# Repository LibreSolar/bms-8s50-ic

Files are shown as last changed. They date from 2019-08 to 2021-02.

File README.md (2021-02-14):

# BMS 8S50 IC

 First boards tested, some issues might still be open.

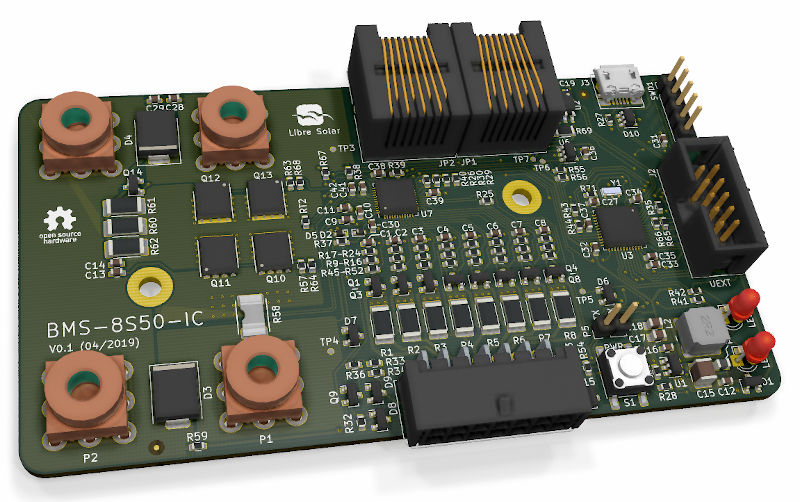
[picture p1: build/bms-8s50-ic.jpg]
BMS 8S50 IC


Schematic: [PDF file](https://github.com/LibreSolar/bms-8s50-ic/raw/master/build/bms-8s50-ic_schematic.pdf)

Bill of Materials: [CSV file](build/bms-8s50-ic_bom.csv) or [interactive HTML BOM](https://libre.solar/bms-8s50-ic/build/bms-8s50-ic_ibom.html)

Firmware repository: [LibreSolar/bms-firmware](https://github.com/LibreSolar/bms-firmware)

## Features:

- 3 to 8 Li-ion cells (e.g. LiFePO4)
- Integrated high-side MOSFET switch and current sensor
- Balancing current approx. 150 mA
- STM32L452 ARM Cortex-M4 microcontroller
- Built-in CAN communication interface and UEXT extension connector

## Firmware

The firmware is developed in a separate repository [LibreSolar/bms-firmware](https://github.com/LibreSolar/bms-firmware).

## Housing

The PCB is designed such that a heat sink can be easily attached at the bottom. The following images show a draft idea for the housing. The files of the heat sink and the cover can be found in the `housing` folder as native FreeCAD files.

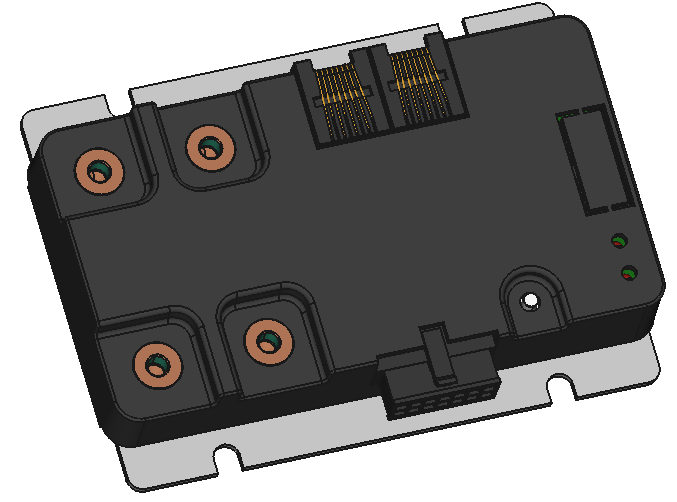
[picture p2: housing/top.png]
Housing top side


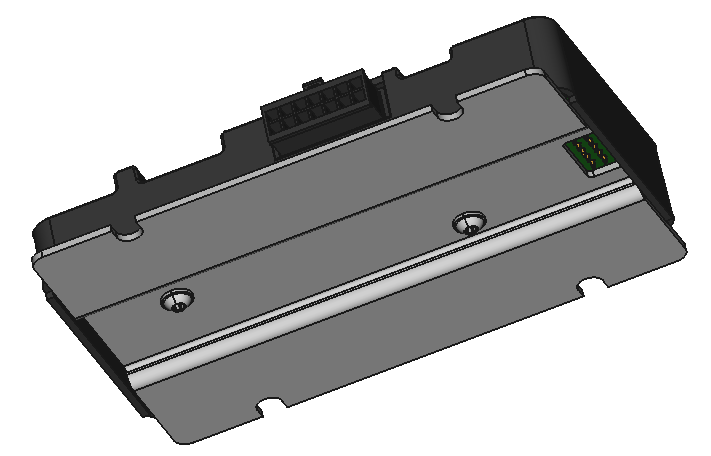
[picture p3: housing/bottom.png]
Housing bottom side with heat sink


## Important Notice

The PCBs have not been tested regarding EMC and other regulations. If you reproduce the boards, you use them at your own risk and responsibility.

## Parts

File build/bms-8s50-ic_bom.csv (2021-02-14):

Component | References | Value | Footprint | Description | Quantity Per PCB | Manufacturer | PartNumber | Remarks | Config | DNF
1 | C37 C41 C42 | 4.7n | C_0603_1608 | Unpolarized capacitor | 3 | Yageo | CC0603KRX7R9BB472
2 | C10 | 10n | C_0603_1608 | Unpolarized capacitor | 1
3 | C1 C2 C3 C4 C5 C6 C7 C8 C20 | 47n | C_0603_1608 | Unpolarized capacitor | 9 | Yageo | CC0603KRX7R9BB473
4 | C13 C14 C16 C19 C27 C28 C29 C31 C32 C33 C34 C36 C38 | 100n | C_0603_1608 | Unpolarized capacitor | 13 | Yageo | CC0603KRX7R9BB104
5 | C30 | 470n | C_0603_1608 | Unpolarized capacitor | 1
6 | C9 C11 C12 | 1u | C_0603_1608 | Unpolarized capacitor | 3 | Murata | GRT188R61H105KE13D | 50V, X5R
7 | C39 | 1u | C_0603_1608 | Unpolarized capacitor | 1
8 | C15 | 4.7u | C_1210_3225 | Unpolarized capacitor | 1 | Murata | GRM31CR71H475MA12L
9 | C21 | 4.7u | C_1206_3216 | Unpolarized capacitor | 1 | Murata | GRM31CR71H475MA12L
10 | C35 | 4.7u | C_0603_1608 | Unpolarized capacitor | 1 | Murata | GRM188R61A475KE15D | 10V
11 | C17 C18 | 10u | C_0805_2012 | Unpolarized capacitor | 2 | Murata | GRM21BR61E106KA73L | 25V
12 | D8 D9 | 12V | D_SOT-23_ANK | Diode zener | 2 | ON Semiconductor | SZBZX84C12LT3G | Alternative: Diodes Inc. BZX84C12-7-F
13 | D1 D6 D7 | BAV70 | SOT-23 | Dual 100V 215mA high-speed switching diodes, common cathode, SOT-23 | 3 | ON Semiconductor | BAV70LT1G | Alternative: Nexperia BAV70,215
14 | D11 D12 | NRVTS260ESFT1G | D_SOD-123 | Schottky diode | 2 | On Semiconductor | NRVTS260ESFT1G | Alternative: Nexperia PMEG6020ER,115
15 | D2 D5 | PMEG6002 | D_SOD-523 | Diode Schottky | 2 | Nexperia | PMEG6002EBF
16 | D3 D4 | SMCJ36A | D_SMC | Diode Schottky | 2 | Bourns | SMCJ24A
17 | D10 | USBLC6-2SC6 | SOT-23-6 |  | 1 | STMicroelectronics | USBLC6-2SC6 | Alternative: WE-TVS 82400102
18 | J1 | Conn_01x10 | Molex_Micro-Fit_3.0_43045-1400_2x07_P3.00mm_Horizontal | Generic connector, double row, 02x07, top/bottom pin numbering scheme (row 1: 1...pins_per_row, row2: pins_per_row+1 ... num_pins), script generated (kicad-library-utils/schlib/autogen/connector/) | 1 | Würth | 66201421022
19 | J2 | UEXT | Box_Header_2x05x2.54mm_Straight | Olimex UEXT connector (2x5 box header) | 1 | Würth | 61201021621
20 | J3 | USB_B_Micro | USB_Micro-B_10103594-0001LF | USB Micro Type B connector | 1 | Amphenol FCI | 10103594-0001LF
21 | JP3 | Jumper_NC_Small | PinHeader_1x02_P2.54mm_Vertical | Jumper, normally closed, small symbol | 1
22 | JP1 JP2 | RJ45_NS | RJ45_8P8C |  | 2 | FCI / Amphenol | 54602-908LF
23 | L1 | 4.7uH | L_0805_2012Metric | Inductor, small symbol | 1 | Murata | LQM21PN4R7NGRD
24 | L2 | 47uH | Bourns_SRN6045TA | Inductor, small symbol | 1 | Tayo Yuden | NR6045T470M | Alternative: Bourns SRR6045TA-470Y
25 | LED1 LED2 | LED | LED_0603_D3.0mm |  | 2
26 | P1 P2 P4 | CONN_01X01 | Wuerth_WP-THRBU_74650195 | Generic screw terminal, single row, 01x01, script generated (kicad-library-utils/schlib/autogen/connector/) | 3 | Wuerth | 74650195
27 | P3 | CONN_01X01 | Wuerth_WP-THRBU_74650195 | Generic screw terminal, single row, 01x01, script generated (kicad-library-utils/schlib/autogen/connector/) | 1 | Wuerth
28 | P5 | CONN_01X02 | PinHeader_1x02_P2.54mm_Vertical | Generic connector, single row, 01x02, script generated (kicad-library-utils/schlib/autogen/connector/) | 1
29 | Q10 Q11 Q12 Q13 | BSC016N06NS | 5X6_MOSFET | Transistor N-MOSFET (general) | 4 | Infineon | BSC016N06NS
30 | Q4 Q5 Q6 Q7 Q8 Q14 Q15 | BSS138 | SOT-23 | Transistor N-MOSFETwith substrate diode (general) | 7 | ON Semiconductor / Fairchild | BSS138
31 | Q1 Q2 Q3 Q9 | NDS0605 | SOT-23 | Transistor P-MOSFET with substrate diode (general) | 4 | ON Semiconductor / Fairchild | NDS0605
32 | R58 | 0.5m | R_Shunt_2512 | Resistor | 1 | Vishay / Dale | WSLF2512L5000FEA | Alternative: Bourns CSS2H-2512R-L500F
33 | R72 | 4R7 | R_0603_1608 | Resistor | 1 | Yageo | RC0603FR-071KL
34 | R1 R2 R3 R4 R5 R6 R7 R8 | 33 | R_2010_5025 | Resistor | 8 | Yageo | RC2010JK-0733RL
35 | R37 R64 R67 R68 R71 | 100 | R_0603_1608 | Resistor | 5 | Yageo | RC0603FR-07100RL
36 | R69 | 120 | R_1206_3216 | Resistor | 1 | Yageo | RC1206FR-07120RL
37 | R60 R61 R62 | 330 | R_2010_5025 | Resistor | 3 | Yageo | RC2010JK-07330RL
38 | R17 R18 R19 R20 R21 R22 R23 R24 R25 R36 R38 R41 R42 R54 | 1k | R_0603_1608 | Resistor | 14 | Yageo | RC0603FR-071KL
39 | R39 R55 R56 R65 R66 | 2.2k | R_0603_1608 | Resistor | 5 | Yageo | RC0603FR-072K2L
40 | R26 R30 R33 R34 R45 R46 R47 R48 R49 R50 R51 R52 | 10k | R_0603_1608 | Resistor | 12 | Yageo | RC0603FR-0710KL
41 | R29 R31 R40 R44 | 22k | R_0603_1608 | Resistor | 4 | Yageo | RC0603FR-0722KL
42 | R28 | 50.5k | R_0603_1608 | Resistor | 1 | Yageo | RC0603FR-0750K5L
43 | R9 R10 R11 R12 R13 R14 R15 R16 R27 R43 R73 | 330k | R_0603_1608 | Resistor | 11 | Yageo | RC0603FR-07330KL
44 | R32 | 1M | R_0603_1608 | Resistor | 1 | Yageo
45 | R35 R53 R57 R63 R70 | 1M | R_0603_1608 | Resistor | 5 | Yageo | RC0603FR-071ML
46 | RT2 | 10k | R_0603_1608 |  | 1 | TDK | NTCG163JF103FT1S
47 | S1 | SW_PUSH | SW_SPST_6mm | Button | 1
48 | SWD1 | ST_Nucleo_SWD_5p | PinHeader_1x05_P2.54mm_Vertical | STM32 Nucleo Board SWD connector (5 pins w/o SWO) | 1
49 | U6 | 24AA32 | SOT-23-5 | Microchip 24AAxx/24LCxx I2C EEPROM, SOT-23-5 | 1 | Microchip | 24AA32AFT-I/OT
50 | U7 | ISL94202 | QFN-48-1EP_6x6mm_P0.4mm_EP4.3x4.3mm | Standalone 3 to 8 Cell Li-Ion Battery Pack Monitor | 1 | Intersil | ISL94202IRTZ-T7A
51 | U3 | STM32L452CCU6 | QFN-48-1EP_7x7mm_P0.5mm_EP5.6x5.6mm | ARM Cortex-M4 MCU, 256KB flash, 160KB RAM, 80MHz, 1.71-3.6V, 38 GPIO, UFQFPN-48 | 1 | ST Microelectronics | STM32L452CCU6
52 | U2 | TCAN334 | SOIC-8_3.9x4.9mm_Pitch1.27mm | High-Speed CAN Transceiver, 1Mbps, 3.3V supply, low power standby mode, shutdown mode, SOT-23-8/SOIC-8 | 1 | Texas Instruments | TCAN334DR
53 | U1 | TPS560430X | SOT-23-6 | SIMPLE SWITCHER® 4V to 60V, 600mA Step-Down Regulator with Low Iq | 1 | Texas Instruments | TPS560430XDBVR
54 | Y1 | 8MHz | Resonator_Murata_CSTNE | Two pin crystal | 1 | Murata | CSTNE8M00GH5C000R0 | 0.07%

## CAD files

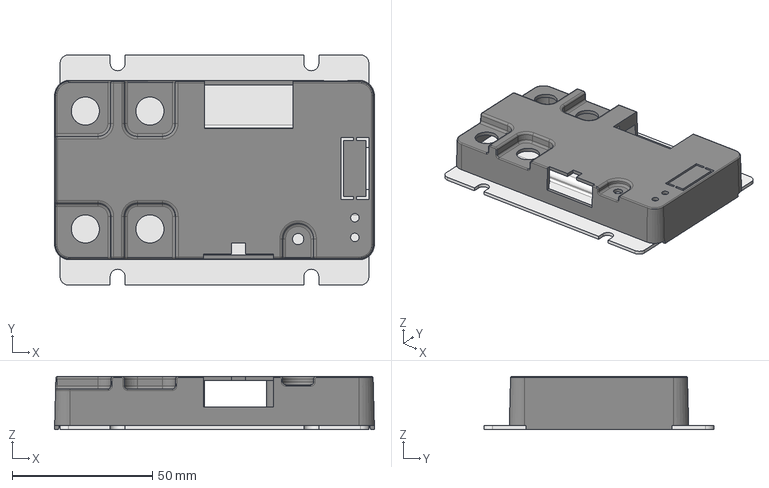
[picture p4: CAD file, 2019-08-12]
housing/bms-8s50-ic.FCStd
114.0 x 82.0 x 19.0 mm
Heatsink
Cover

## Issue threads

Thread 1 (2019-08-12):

Cell connector: Change to JST PH?

martinjaeger, 2019-08-12:
The current PCB uses Würth WR-MPC3 connectors (compatible to Molex Microfit).

These connectors are used quite often in the industry, but not very popular among makers, as they require special crimping tools.

JST PH connectors are quite popular for BMSs on ebay, but are only single-row and require more board space.

Any other good ideas for a connector?

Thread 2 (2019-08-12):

Add marking for Bat+/- and Ext+/- on PCB

martinjaeger, 2019-08-12:
The high power connectors are currently not well marked (forgotten during PCB design).

They should get a marking of the battery-internal +/- terminal and the external (load/charger) +/- terminals.

Closed 2020-05-08.

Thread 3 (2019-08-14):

Add free running diodes parallel to MOSFETs

xsider, 2019-08-14:
Two shottky diodes should be added, parallel to the body diodes inside the MOSFETs. We had maybe a overheating event occured at Switch-N-Sense when huge amount of currenct was sink from the battery while the charge mosfet was open, so the body diode was used. The body diode is a bad one (big voltage drop).

martinjaeger, 2019-08-14:
This can be solved in firmware with improved control (ideal diode control). Monitor the current and as soon as it goes into discharging direction switch on the charge MOSFET even if charging is not allowed at that moment.

martinjaeger, 2019-08-18:
Just saw that the ISL94202 supports ideal diode control out of the box. Look at the DFODUV and CFODOV settings.

martinjaeger, 2019-08-18:
Closing this issue, as solutions without hardware change exist. Please reopen if you disagree.

martinjaeger, 2021-06-24:
FYI: I have implemented the ideal diode control today.

https://github.com/LibreSolar/bms-firmware/commit/42f2da214415df28c67f6d3dba1b5db2b75b85b2

Closed 2019-08-18.

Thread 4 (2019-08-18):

Increase shunt resistor value for higher charge current

martinjaeger, 2019-08-18:
The ISL94202 allows maximum 24 mV as charge overcurrent threshold. This corresponds to only 24 A using the current 1 mOhm shunt.

The resistor value should be lowered to 0.5 or 0.4 mOhm.

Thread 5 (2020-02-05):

voltage measurement of cell 1

MatthiasN73, 2020-02-05:
Hi,
I recently finished building the bms-8s50 and encountered a problem with the voltage measurement of cell 1. The measurement is very instable. the voltage oscillates by approximately 200 mV and is about 500 mV to low. After some investigations and bridging R59 the oscillation is gone and near the real value but still to low (150 mV). What is the function of R59?
By the way I studied the datasheet of the ISL94202 and found some issues:
a missing capacitor between VC0 and Ground (47nF)
a missing resistor (1M) between source and gate of Q10 (PCFET)
wrong value of C30 should be a 470nF capacitor
If I have understood the datasheet correctly, the Precharge path should bridge the charge fet in case of to low voltage of one or more cells. But in your case the discharge fet is bridged. Why?

sorry for my english.

martinjaeger, 2020-02-06:
Hi Matthias,
very cool that you rebuilt the BMS. Unfortunately I didn't have much time for it in the past months, so there was not too much progress in testing and firmware of the BMS.

I didn't have any issues with cell voltage measurements in my 4s battery pack so far. But I'll double-check.

The idea for R59 was to decouple the power path from the analog measurement ground. I actually took this idea from the [DieBieMS](https://github.com/DieBieEngineering/DieBieMS).

You are right, a capacitor between VC0 and GND is missing. This might cause some noise in cell 1 measurement, but it should not result in 150 mV offset... but it's definitely an error that should be corrected in next revision. It could be possible to add the capacitor manually attached to R25 in current PCB layout.

Also the value of C30 is wrong, I agree.

I'm using the precharge circuit different from what is stated in the datasheet. I use it to precharge the capacitors of devices connected to the battery before switching the discharge MOSFET on. This prevents high inrush currents. I don't really see the point of precharging the battery (not the capacitors) slowly via resistors, as the BMS could just tell the charger to use low current.

Are you using the new Zephyr-based firmware or did you develop something else yourself?

MatthiasN73, 2020-02-06:
Hello Martin,
Thanks for your quick response.
In my configuration, I use all 8 cells.
I would like to use the zephyr version, but there is no board definition for the STM32F072 mcu and so I cannot flash the compiled firmware.
To get the bms working, I just completed the missing function “isl94202_write_bytes” and “isl94202_read_bytes” in the mbed-version.

martinjaeger, 2020-02-06:
As I'm now quite used to Zephyr, it shouldn't be that much effort to add a board definition for the STM32F072 MCU. I'll try to include that.

However, as I soldered the L4 MCU onto my board, I can't test it for the new BMS.

martinjaeger, 2020-02-06:
Please have a try: https://github.com/LibreSolar/bms-firmware/commit/85969f8416860dc9ba5ee1d79ab26c3384f68910

MatthiasN73, 2020-02-10:
Unfortunately I can’t compile the firmware. Seems to be too big.
The following Errors appear:
firmware-pre.elf section `bss' will not fit in region `SRAM'
region `SRAM' overflowed by 13320 bytes
Any idea?

martinjaeger, 2020-02-10:
Oh yes, the heap size was way too high (which is not necessary). Reduced it to 1024 bytes. Please `git pull` and try again.

Here is the change: https://github.com/LibreSolar/bms-firmware/commit/0e6d23e10f0c196ae55d72aa18770a512bd60185

MatthiasN73, 2020-02-10:
Now build and upload works. Thanks again.

MatthiasN73, 2020-02-10:
This is an automatic reply to your message

 ---------------------------------------------------------------------
 Sie haben eine E-Mail an die Adresse m.neubauer@schenk-ansorge.de geschickt.
 Leider bin ich bis einschließlich 14.02.2020 18:00  nicht im Labor.
 In dringenden Fällen wenden Sie sich bitte an Herrn Gerhard unter
 der Telefonnummer 0391/24468-246 bzw. F.Gerhard@schenk-ansorge.de

 Vielen Dank für Ihr Verständnis.

 ---------------------------------------------------------------------

 File names:    

Oh yes, the heap size was way too high (which is not necessary). Reduced it to 1024 bytes. Please `git pull` and try again.

Here is the change: https://github.com/LibreSolar/bms-firmware/commit/0e6d23e10f0c196ae55d72aa18770a512bd60185

--
You are receiving this because you authored the thread.
Reply to this email directly or view it on GitHub:
https://github.com/LibreSolar/bms-8s50-ic/issues/5#issuecomment-584024162

MatthiasN73, 2020-04-19:
Hi Martin,

after further investigation and reading then ISL94202 datasheet, i discovered the potential cause of this issue.
The VDD Pin of the ISL94202 should conntected to the top of the pack through a low pass filter consisting of a <10 Ohm resistor and a 4.7μF capacitor.
In your circuit VDD is connected through the VBATT low pass filter with an resistor of 100 Ohm.
Currently i've connected D2 through a separat low pass filter (4,7 Ohm / 4.7μF) to BAT+. Now the volatage measurment is okay.
By the way i replaced C39 with a 1µF capacitor, C30 with a 470nF capacitor and add the missing 47nF capacitor at VC0.

Furthermore i increased the shunt resistor to 0.3 mOhm, but the displayed current does'nt match the measured value of my multimeter.
Any ideas?

martinjaeger, 2020-04-23:
Hi Matthias,

just checked with my BMS here and realized that the current measurement is pretty accurate above 1A, but more than 20% off at very low currents.

The reason may be that the firmware doesn't adjust the current sense amplfier gain yet, it is always kept at the default setting (gain 50). The accuracy will probably become better if it is set to 500.

Great that you found the reason for the issue with VBATT measurement. Didn't have time to test it yet, but will try to do that soon, together with fixing the capacitor values. Afterwards I will also update board and schematic :)

martinjaeger, 2020-05-08:
Soldered all the updates you suggested above to my board. Looks a bit ugly now :)

Also the KiCad files should now include all the identified fixes. Please have a look if I forgot something.

I hoped that the added capacitors would also solve the incorrect pack voltage measurement (see [here](https://github.com/LibreSolar/bms-firmware/blob/8ff63999a65384dbe5ab18886f27a3f042b34043/src/bms_isl94202.c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)). Unfortunately, that was not the case here. Did you try out if the pack voltage measurement provided by the chip is correct? I get a pack voltage of around 12.8V, but sum of single cell voltages is 13.1V, which is also what my multimeter tells me.

The shunt resistor is not updated yet (still need to decide which value is suitable, as the current measurement gets inaccurate if the shunt value is too small, as you have seen as well).

MatthiasN73, 2020-05-09:
Hi Martin,

looks good. I replaced the R59 by a 0R resistor, because it affects the measurement as well.
The pack voltage i messured with my multimeter ist 31.0 V (it's a 8S LIPO pack) and the ISL tells a voltage of 31.16.
I think it's pretty okay.

martinjaeger, 2020-05-09:
Ok, that might in fact be the reason. Will try that out aswell and let you know the result.

martinjaeger, 2020-05-11:
Morning! Just had a try with R59 as 0R, but it didn't really improve the pack voltage reading.

Just for clarification: Did you measure above stated values via the ISL94202_VBATT register or with the sum of all single cell voltages (which is how the pack voltage is currently calculated in the firmware).
If I comment out the line referenced above I still get a pack voltage of 12.91V (instead of 13.32V if using the sum of all single cell voltages). The actual voltage measured with the Fluke Multimeter is 13.33V. So the sum of cell voltages is very accurate, while the pack voltage is not at all...

MatthiasN73, 2020-05-11:
Yes, i activated the pack voltage measurement by reading ISL94202_VBATT register.  My multimeter is just a simple PEAKTECH 3335. Maybe it's not very precisely. Will try out the summation of all cells and compare it with the VBATT register value tomorrow.

MatthiasN73, 2020-05-11:
Hi, here are my results:
- sum of cells voltage: 29.68 V
- result of reading VBATT register: 29.79 V
- measurement with multimeter: 29.6 V
I think, this is an acceptable deviation (< 0,5%).

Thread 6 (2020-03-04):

Add pull-down to +5V

martinjaeger, 2020-03-04:
The 5V power supply is floating if no USB is connected. In some cases it was >1V and enabled the SMPS again immediately after shutdown (via D6). A weak pull-down helps to prevent this.

Other option: Remove D6 completely and switch on only via RGO. In that case, the MCU can't be powered if no battery is connected. But that is probably not an issue.

Closed 2020-05-08.

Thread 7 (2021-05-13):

Bus precharge using PCFET pin does not work as intended

martinjaeger, 2021-05-13:
The idea was to use the pin originally intended for slow charging of a deep-discharged battery to slowly charge bus capacitors and prevent high discharge current through the FETs during turn-on.

This does not work as intended, as the gate of Q14 is kept at the top cell voltage and thus allows continuous discharge current through the precharge resistors if EXT+ is pulled low.

Workaround (not using the bus precharge anymore) is to remove Q14.

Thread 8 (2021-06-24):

Strange behaviour of ISL94202 shuts off FETs at 55°C

martinjaeger, 2021-06-24:
According to the ISL94292 manual, xT2 can be used to monitor the FETs.

However, the temperature limit of the FETs is not configurable. If `XT2M` is set to 1 to indicate that it's not measuring cell temperatures, the FETs are still switched off if the temperature at xT2 reaches 55°C and back on when the temperature drops to 50°C again. These thresholds are the same as the default cell overtemperature thresholds, but they don't seem to be read from the same registers.

Below image shows a test where in a first step xT2 (MOSFETs) was heated up (by charging through body diode while discharge FET was off). Afterwards, the external sensor connected to xT1 (Battery) was heated up with a heat gun. As it can be seen, the same error flags are raised (COTF and DOTF). The cell temperature limit is set to 45°C, re-connect to 40°C, which is working fine. The xT2 limits of 55°C and 50°C are not affected.

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

This strange (undocumented) behaviour of the chip is also confirmed here:
https://renesasrulz.com/general/f/general---forum/15530/isl94202-demo-board-fet-temp-issue

Possible solutions (in hardware):

1. Use thermistor directly wired to microcontroller.
2. Adjust xT2 thermistor network to match desired maximum measured MOSFET temperature.

martinjaeger, 2021-06-24:
Interestingly, it's now picking up the same temperature setpoints as the cell overtemperature:

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

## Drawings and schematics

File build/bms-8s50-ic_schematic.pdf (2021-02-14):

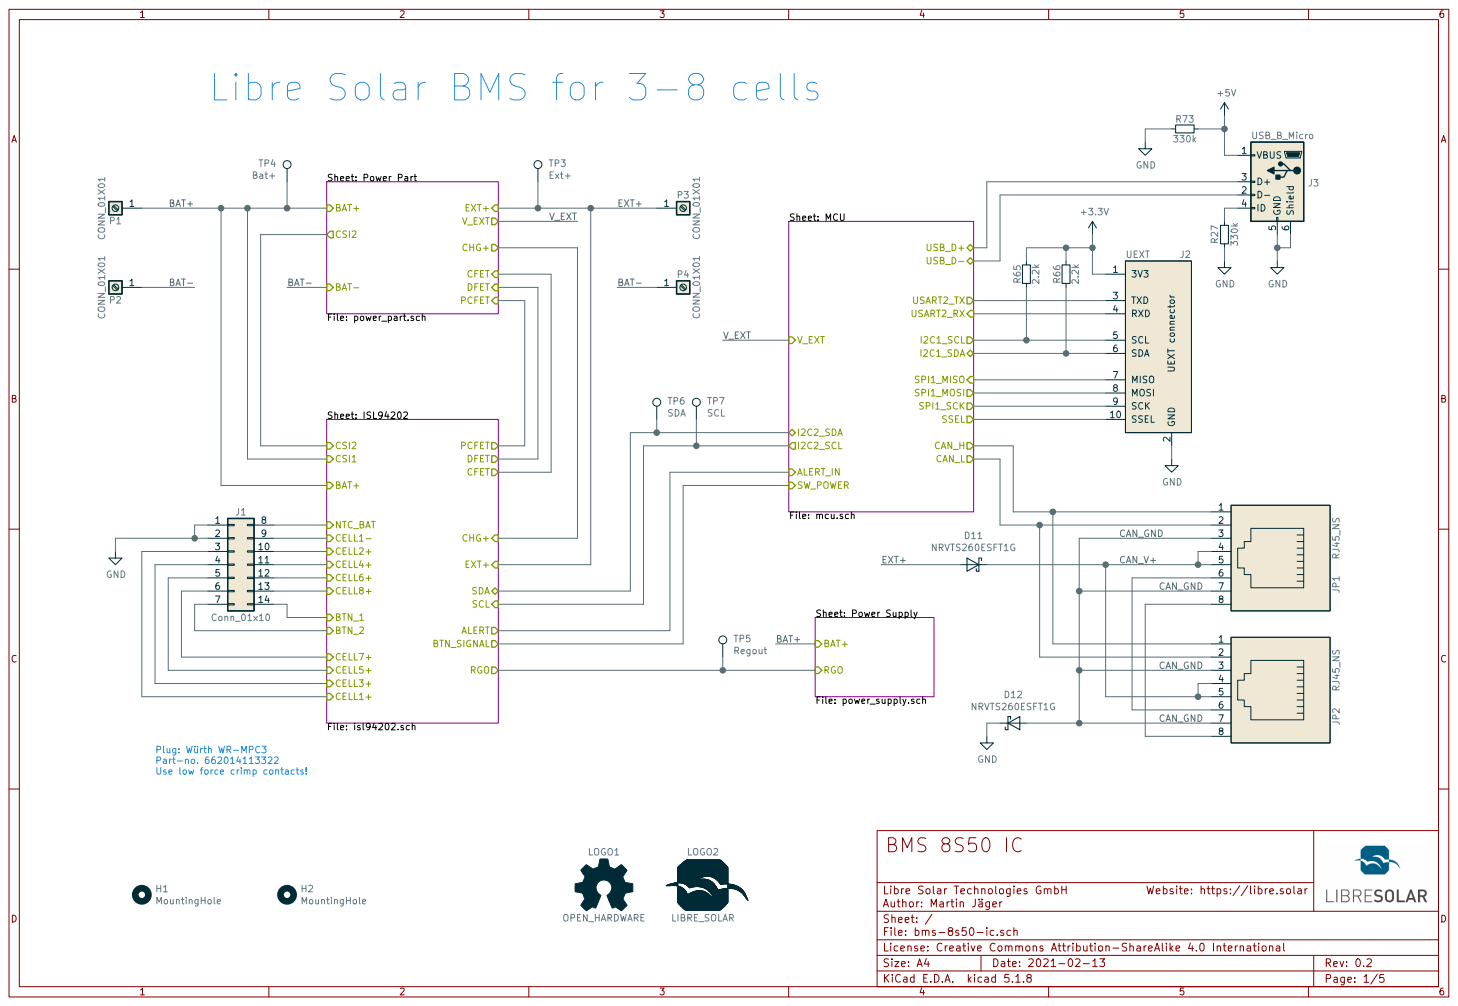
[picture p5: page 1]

Libre Solar BMS for 3-8 cells

2 TXD 3 SCL 5 SDA 6 MISO 7 MOSI 8 SCK 9 UEXT J2

V_EXT BAT- Plug: Würth WR-MPC3 Part-no. 662014113322 Use low force crimp contacts!

CAN_GND 3

Author: Martin Jäger License: Creative Commons Attribution-ShareAlike 4.0 International

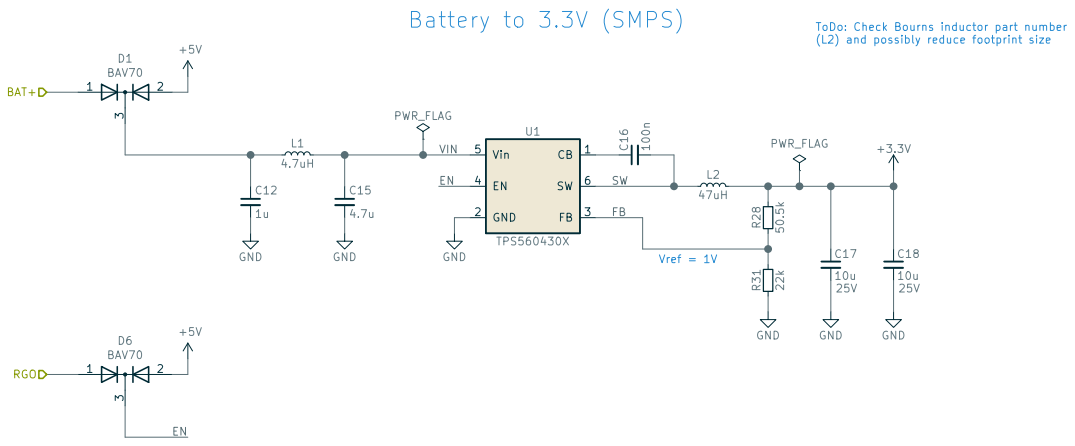
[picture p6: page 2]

(L2) and possibly reduce footprint size Vref = 1V

Author: Martin Jäger License: Creative Commons Attribution-ShareAlike 4.0 International
Sheet: /Power Supply/
File: power_supply.sch

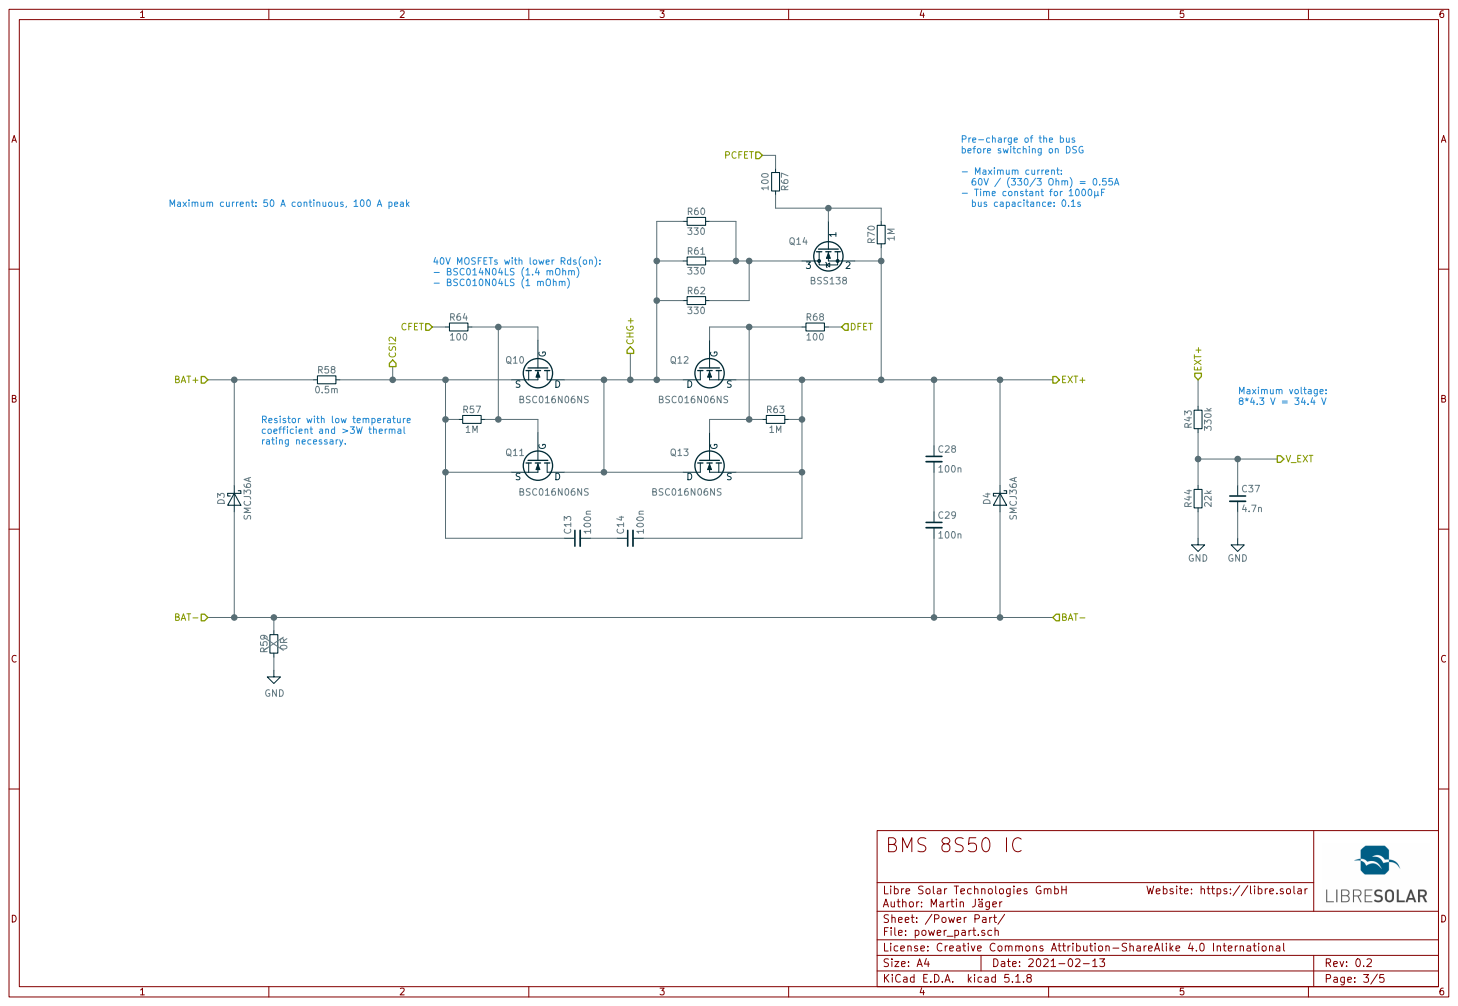
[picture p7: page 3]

Pre-charge of the bus
before switching on DSG

Maximum current: 50 A continuous, 100 A peak

40V MOSFETs with lower Rds(on):
- BSC014N04LS (1.4 mOhm)
- BSC010N04LS (1 mOhm)

Resistor with low temperature
coefficient and >3W thermal rating necessary.

Author: Martin Jäger License: Creative Commons Attribution-ShareAlike 4.0 International

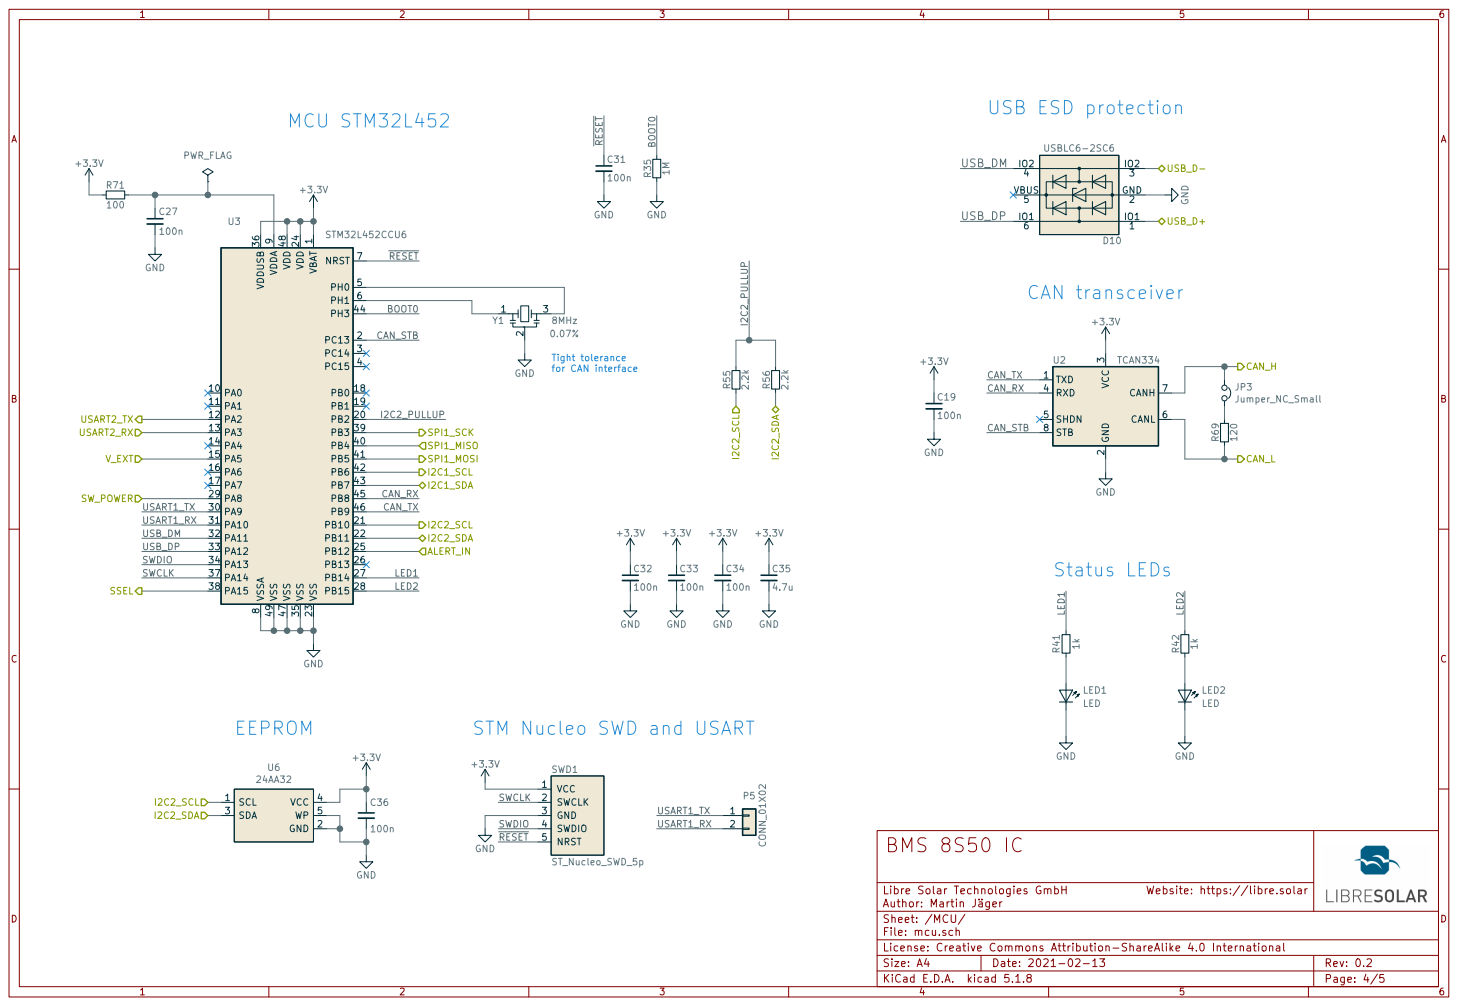
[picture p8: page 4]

3 RXD 4 SHDN 5 CANL 6 CANH 7 STB 8 U2 TCAN334 R71

8 U3 STM32L452CCU6 GND 2 VCC 4 SCL 1 SDA 3 WP 5 U6

9 VDDUSB 36 VSS 23 VSS 35 VSS 47 VSS 49 VSSA

LED GND
STM Nucleo SWD and USART

Author: Martin Jäger License: Creative Commons Attribution-ShareAlike 4.0 International

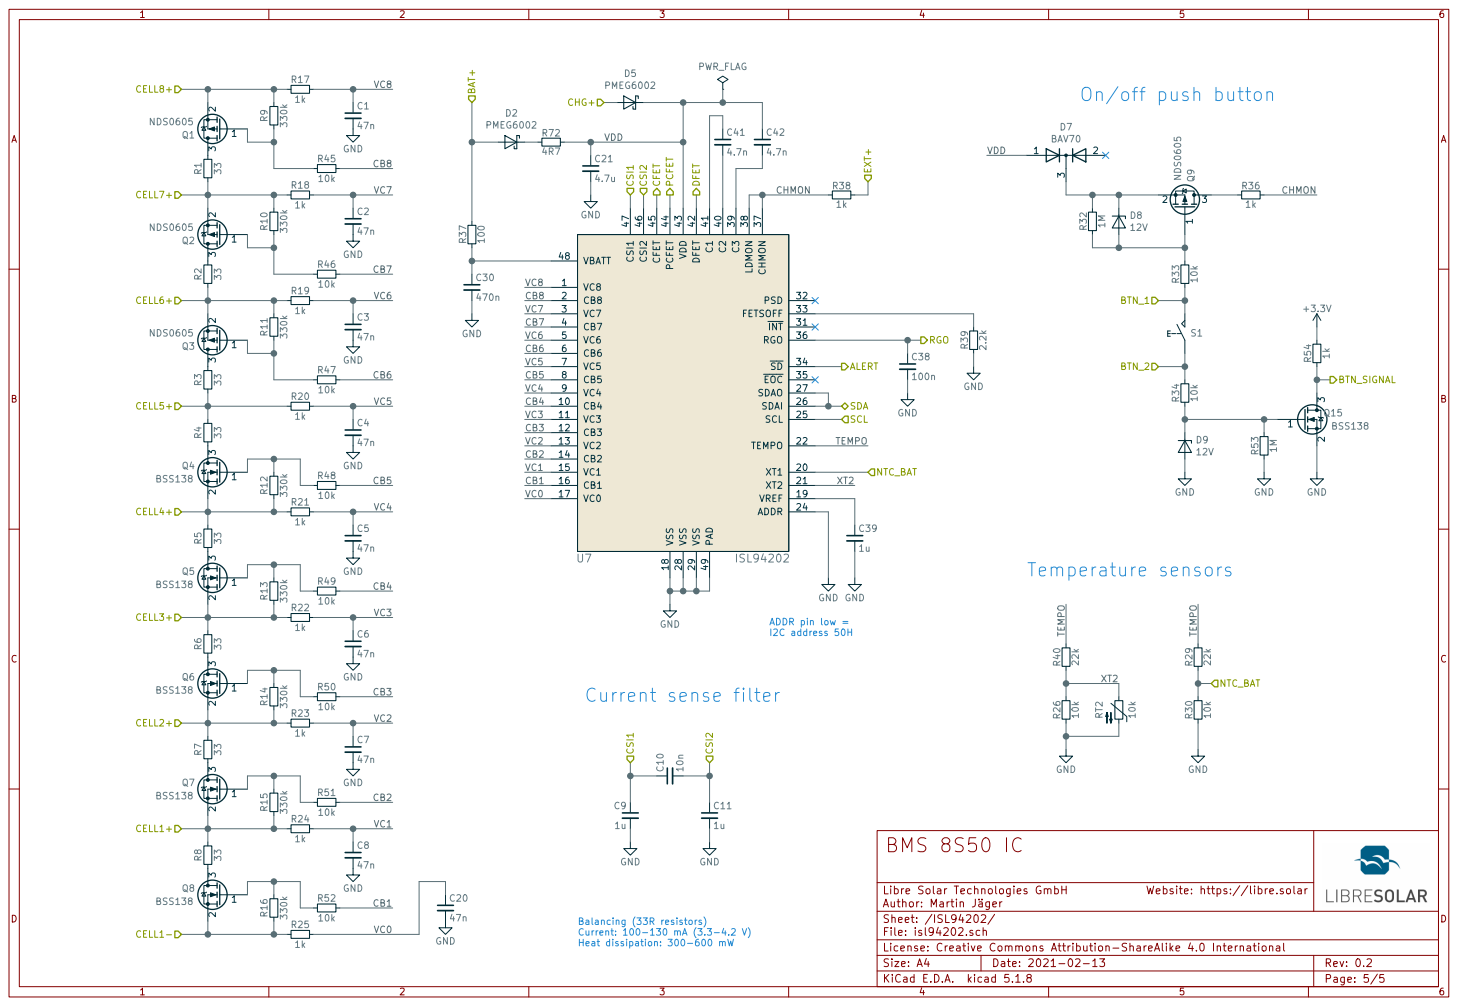
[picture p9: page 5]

On/off push button

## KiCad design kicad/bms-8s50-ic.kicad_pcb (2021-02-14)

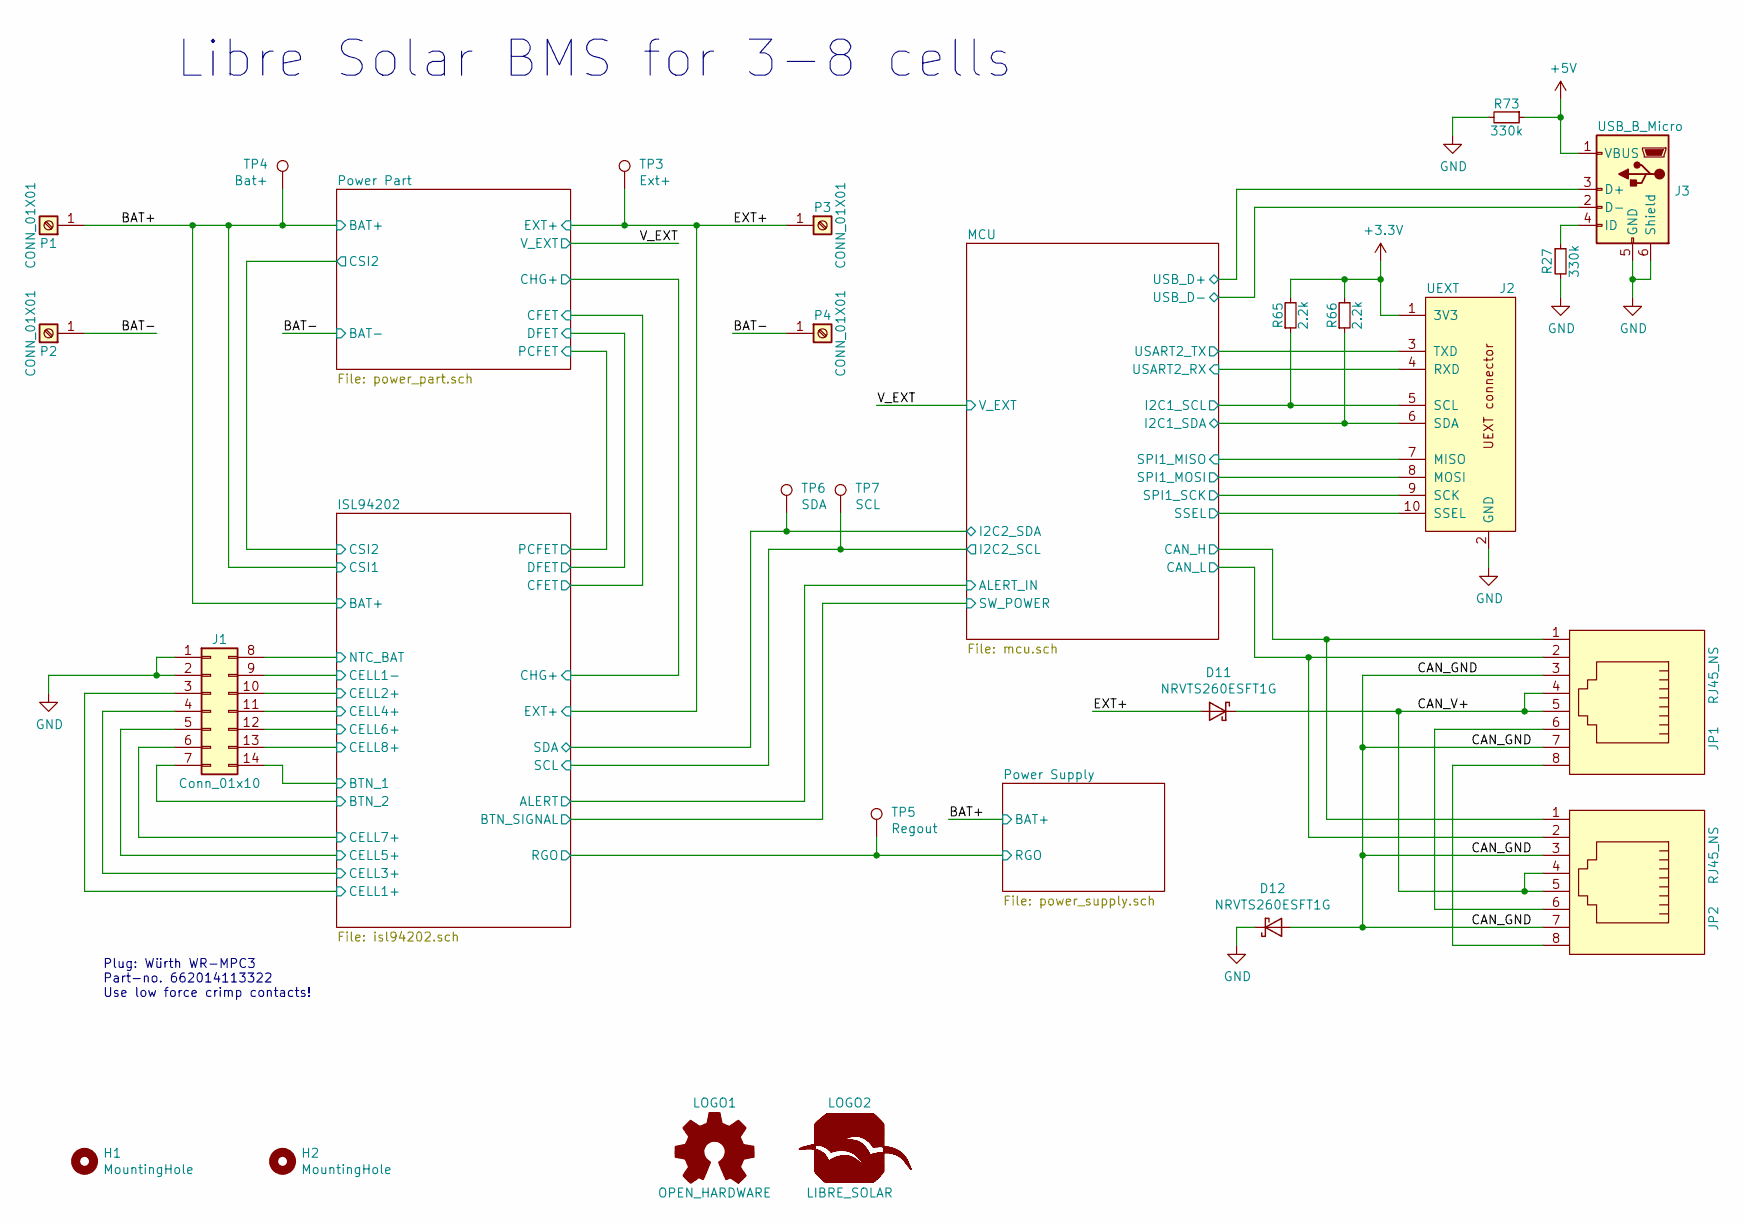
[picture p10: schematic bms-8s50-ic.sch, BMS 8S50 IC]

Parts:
D11, D12: NRVTS260ESFT1G; D_SOD-123; PartNumber NRVTS260ESFT1G
H1, H2: MountingHole; MountingHole_3.2mm_M3_Pad
J1: Conn_01x10; Molex_Micro-Fit_3.0_43045-1400_2x07_P3.00mm_Horizontal; PartNumber 66201421022
J2: UEXT; Box_Header_2x05x2.54mm_Straight; PartNumber 61201021621
J3: USB_B_Micro; USB_Micro-B_10103594-0001LF; PartNumber 10103594-0001LF
JP1, JP2: RJ45_NS; RJ45_8P8C; PartNumber 54602-908LF
LOGO1: OPEN_HARDWARE; OSHW-Logo_5.7x6mm_SilkScreen
LOGO2: LIBRE_SOLAR; LIBRESOLAR_LOGO
P1, P2, P4: CONN_01X01; Wuerth_WP-THRBU_74650195; PartNumber 74650195
P3: CONN_01X01; Wuerth_WP-THRBU_74650195
R27, R73: 330k; R_0603_1608; PartNumber RC0603FR-07330KL
R65, R66: 2.2k; R_0603_1608; PartNumber RC0603FR-072K2L
TP3: Ext+; TestPoint_1mm_pad
TP4: Bat+; TestPoint_1mm_pad
TP5: Regout; TestPoint_1mm_pad
TP6: SDA; TestPoint_1mm_pad
TP7: SCL; TestPoint_1mm_pad

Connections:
+3V3: J2.1 (3V3), R65.2, R66.2; also elsewhere on the board
+5V: J3.1 (VBUS), R73.1; also elsewhere on the board
/BAT+: P1.1, TP4.1; also elsewhere on the board
/BAT-: P2.1, P4.1; also elsewhere on the board
/CAN_GND: D12.2 (A), JP1.3, JP1.7, JP2.3, JP2.7
/CAN_V+: D11.1 (K), JP1.4, JP1.5, JP2.4, JP2.5
/EXT+: D11.2 (A), P3.1, TP3.1; also elsewhere on the board
/ISL94202/BTN_1: J1.14; also elsewhere on the board
/ISL94202/BTN_2: J1.7; also elsewhere on the board
/ISL94202/CELL1+: J1.3; also elsewhere on the board
/ISL94202/CELL1-: J1.9; also elsewhere on the board
/ISL94202/CELL2+: J1.10; also elsewhere on the board
/ISL94202/CELL3+: J1.4; also elsewhere on the board
/ISL94202/CELL4+: J1.11; also elsewhere on the board
/ISL94202/CELL5+: J1.5; also elsewhere on the board
/ISL94202/CELL6+: J1.12; also elsewhere on the board
/ISL94202/CELL7+: J1.6; also elsewhere on the board
/ISL94202/CELL8+: J1.13; also elsewhere on the board
/ISL94202/NTC_BAT: J1.8; also elsewhere on the board
/ISL94202/RGO: TP5.1; also elsewhere on the board
/MCU/CAN_H: JP1.1, JP2.1; also elsewhere on the board
/MCU/CAN_L: JP1.2, JP2.2; also elsewhere on the board
/MCU/I2C1_SCL: J2.5 (SCL), R65.1; also elsewhere on the board
/MCU/I2C1_SDA: J2.6 (SDA), R66.1; also elsewhere on the board
/MCU/I2C2_SCL: TP7.1; also elsewhere on the board
/MCU/I2C2_SDA: TP6.1; also elsewhere on the board
/MCU/SPI1_MISO: J2.7 (MISO); also elsewhere on the board
/MCU/SPI1_MOSI: J2.8 (MOSI); also elsewhere on the board
/MCU/SPI1_SCK: J2.9 (SCK); also elsewhere on the board
/MCU/SSEL: J2.10 (SSEL); also elsewhere on the board
/MCU/USART2_RX: J2.4 (RXD); also elsewhere on the board
/MCU/USART2_TX: J2.3 (TXD); also elsewhere on the board
/MCU/USB_D+: J3.3 (D+); also elsewhere on the board
/MCU/USB_D-: J3.2 (D-); also elsewhere on the board
GND: D12.1 (K), J1.1, J1.2, J2.2 (GND), J3.5 (GND), J3.6 (Shield), R27.2, R73.2; also elsewhere on the board
unnamed: J3.4 (ID), R27.1
unnamed: JP1.6, JP2.6
unnamed: JP1.8, JP2.8

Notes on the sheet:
Plug: Würth WR-MPC3 Part-no. 662014113322 Use low force crimp contacts!
Libre Solar BMS for 3-8 cells

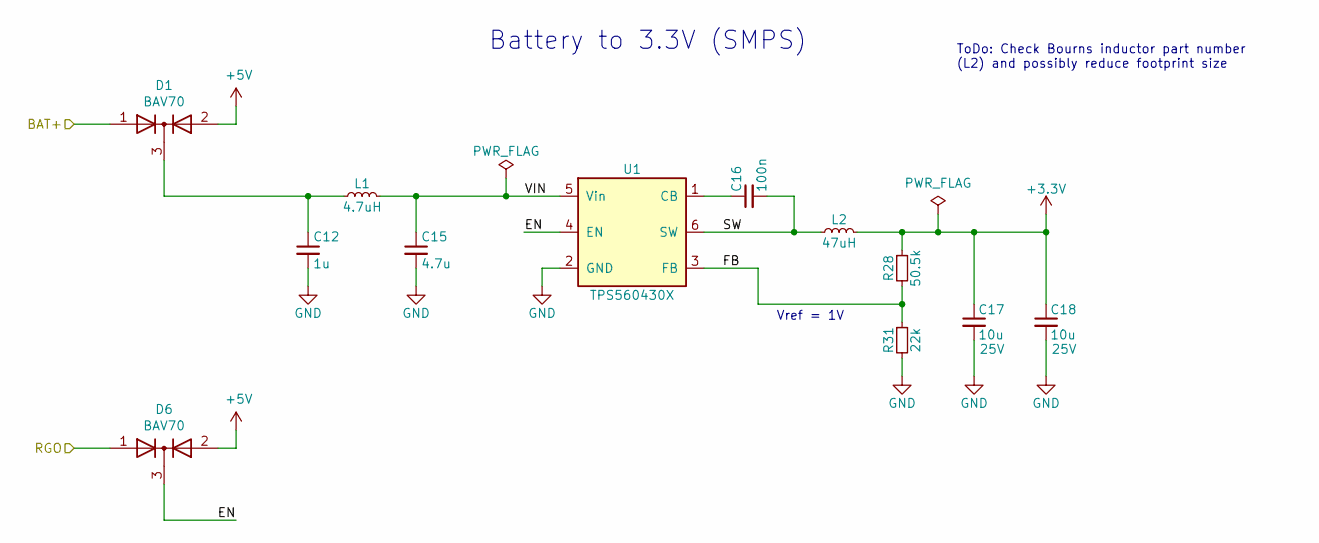
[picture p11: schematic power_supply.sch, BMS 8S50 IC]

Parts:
C12: 1u; C_0603_1608; PartNumber GRT188R61H105KE13D
C15: 4.7u; C_1210_3225; PartNumber GRM31CR71H475MA12L
C16: 100n; C_0603_1608; PartNumber CC0603KRX7R9BB104
C17, C18: 10u; C_0805_2012; PartNumber GRM21BR61E106KA73L
D1, D6: BAV70; SOT-23; PartNumber BAV70LT1G
L1: 4.7uH; L_0805_2012Metric; PartNumber LQM21PN4R7NGRD
L2: 47uH; Bourns_SRN6045TA; PartNumber NR6045T470M
R28: 50.5k; R_0603_1608; PartNumber RC0603FR-0750K5L
R31: 22k; R_0603_1608; PartNumber RC0603FR-0722KL
U1: TPS560430X; SOT-23-6; PartNumber TPS560430XDBVR

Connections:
+3V3: C17.1, C18.1, L2.2, R28.1; also elsewhere on the board
+5V: D1.2 (A), D6.2 (A); also elsewhere on the board
/BAT+: D1.1 (A); also elsewhere on the board
/ISL94202/RGO: D6.1 (A); also elsewhere on the board
/Power Supply/EN: D6.3 (K), U1.4 (EN)
/Power Supply/FB: R28.2, R31.1, U1.3 (FB)
/Power Supply/SW: C16.2, L2.1, U1.6 (SW)
/Power Supply/VIN: C15.1, L1.2, U1.5 (Vin)
GND: C12.2, C15.2, C17.2, C18.2, R31.2, U1.2 (GND); also elsewhere on the board
unnamed: C12.1, D1.3 (K), L1.1
unnamed: C16.1, U1.1 (CB)

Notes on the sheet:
Battery to 3.3V (SMPS)
ToDo: Check Bourns inductor part number (L2) and possibly reduce footprint size
Vref = 1V

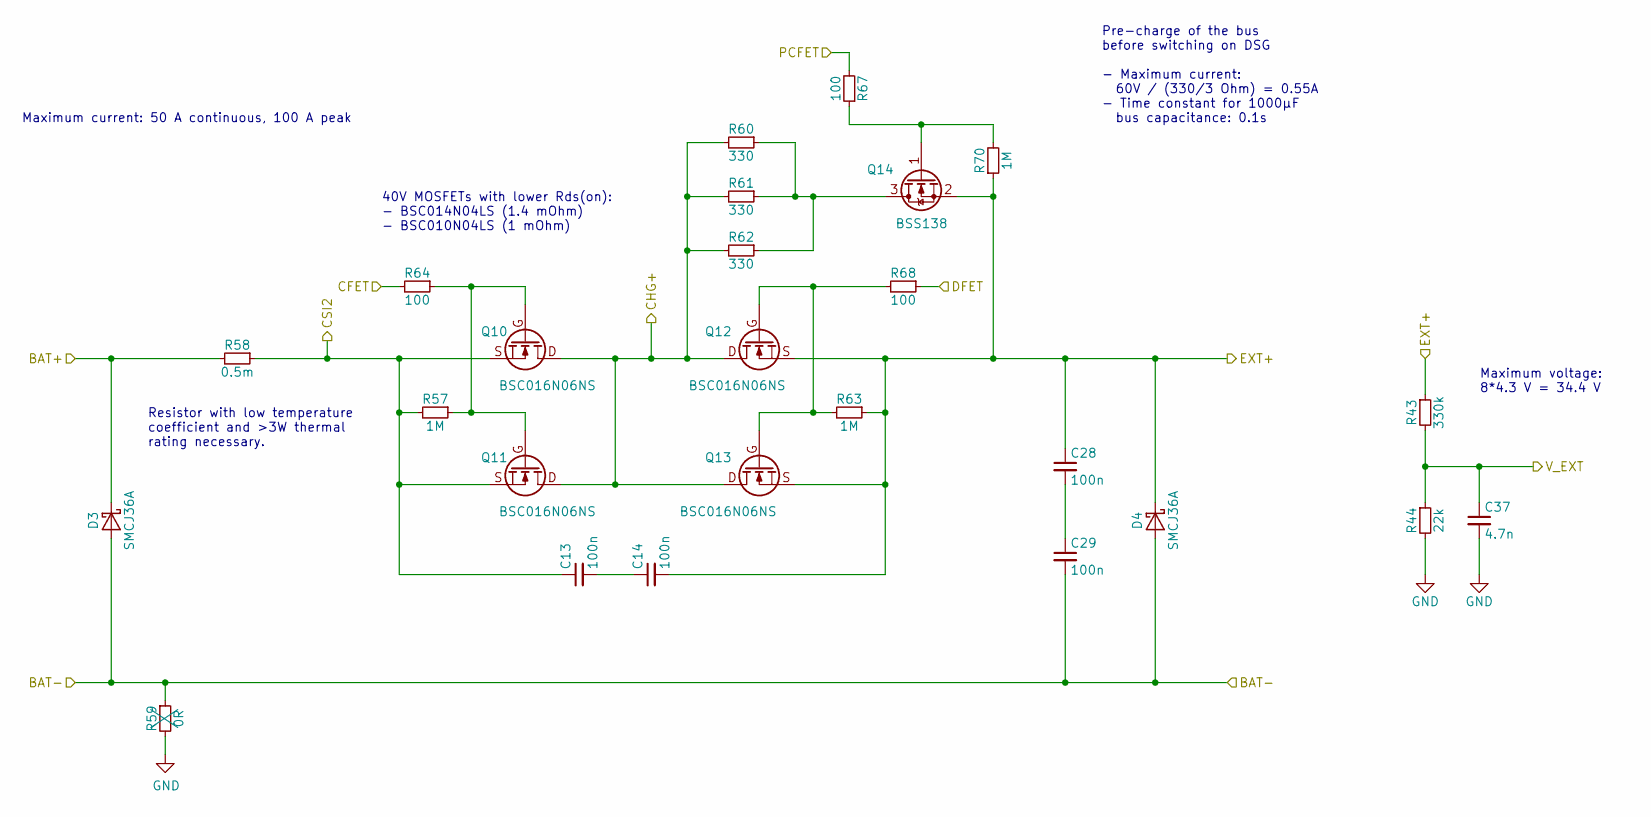
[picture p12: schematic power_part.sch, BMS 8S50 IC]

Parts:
C13, C14, C28, C29: 100n; C_0603_1608; PartNumber CC0603KRX7R9BB104
C37: 4.7n; C_0603_1608; PartNumber CC0603KRX7R9BB472
D3, D4: SMCJ36A; D_SMC; PartNumber SMCJ24A
Q10, Q11, Q12, Q13: BSC016N06NS; 5X6_MOSFET; PartNumber BSC016N06NS
Q14: BSS138; SOT-23; PartNumber BSS138
R43: 330k; R_0603_1608; PartNumber RC0603FR-07330KL
R44: 22k; R_0603_1608; PartNumber RC0603FR-0722KL
R57, R63, R70: 1M; R_0603_1608; PartNumber RC0603FR-071ML
R58: 0.5m; R_Shunt_2512; PartNumber WSLF2512L5000FEA
R59: 0R; R_0603_1608; PartNumber RC0603FR-070RL
R60, R61, R62: 330; R_2010_5025; PartNumber RC2010JK-07330RL
R64, R67, R68: 100; R_0603_1608; PartNumber RC0603FR-07100RL

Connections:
/BAT+: D3.1 (K), R58.2; also elsewhere on the board
/BAT-: C29.2, D3.2 (A), D4.2 (A), R59.1; also elsewhere on the board
/EXT+: C14.2, C28.1, D4.1 (K), Q12.S, Q13.S, Q14.2 (S), R43.1, R63.1, R70.1; also elsewhere on the board
/ISL94202/CFET: R64.2; also elsewhere on the board
/ISL94202/CHG+: Q10.D, Q11.D, Q12.D, Q13.D, R60.2, R61.2, R62.2; also elsewhere on the board
/ISL94202/CSI2: C13.1, Q10.S, Q11.S, R57.2, R58.1; also elsewhere on the board
/ISL94202/DFET: R68.1; also elsewhere on the board
/ISL94202/PCFET: R67.2; also elsewhere on the board
/V_EXT: C37.1, R43.2, R44.1; also elsewhere on the board
GND: C37.2, R44.2, R59.2; also elsewhere on the board
unnamed: C13.2, C14.1
unnamed: C28.2, C29.1
unnamed: Q10.G, Q11.G, R57.1, R64.1
unnamed: Q12.G, Q13.G, R63.2, R68.2
unnamed: Q14.1 (G), R67.1, R70.2
unnamed: Q14.3 (D), R60.1, R61.1, R62.1

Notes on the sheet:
Pre-charge of the bus before switching on DSG - Maximum current: 60V / (330/3 Ohm) = 0.55A - Time constant for 1000µF bus capacitance: 0.1s
Resistor with low temperature coefficient and >3W thermal rating necessary.
Maximum current: 50 A continuous, 100 A peak
40V MOSFETs with lower Rds(on): - BSC014N04LS (1.4 mOhm) - BSC010N04LS (1 mOhm)
Maximum voltage: 8*4.3 V = 34.4 V

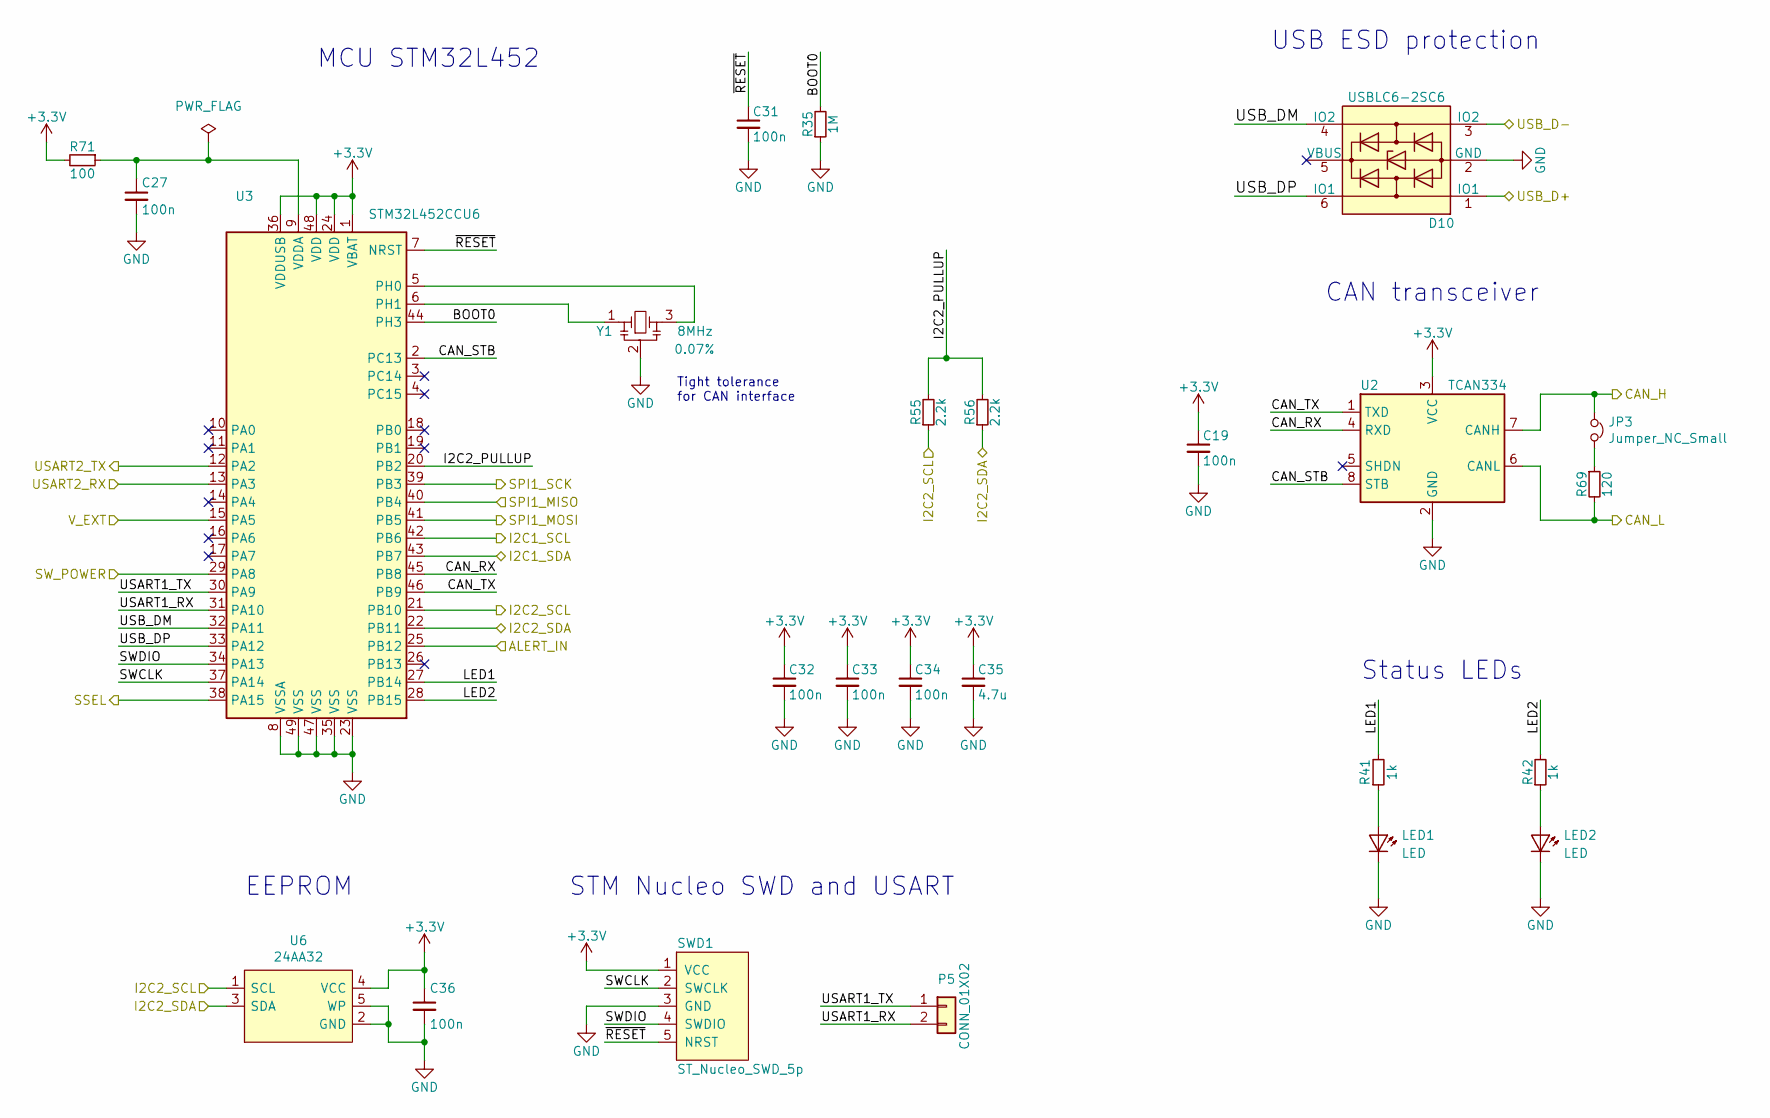
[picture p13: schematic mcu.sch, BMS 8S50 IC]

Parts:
C19, C27, C31, C32, C33, C34, C36: 100n; C_0603_1608; PartNumber CC0603KRX7R9BB104
C35: 4.7u; C_0603_1608; PartNumber GRM188R61A475KE15D
D10: USBLC6-2SC6; SOT-23-6; PartNumber USBLC6-2SC6
JP3: Jumper_NC_Small; PinHeader_1x02_P2.54mm_Vertical
LED1, LED2: LED; LED_0603_D3.0mm
P5: CONN_01X02; PinHeader_1x02_P2.54mm_Vertical
R35: 1M; R_0603_1608; PartNumber RC0603FR-071ML
R41, R42: 1k; R_0603_1608; PartNumber RC0603FR-071KL
R55, R56: 2.2k; R_0603_1608; PartNumber RC0603FR-072K2L
R69: 120; R_1206_3216; PartNumber RC1206FR-07120RL
R71: 100; R_0603_1608; PartNumber RC0603FR-07100RL
SWD1: ST_Nucleo_SWD_5p; PinHeader_1x05_P2.54mm_Vertical
U2: TCAN334; SOIC-8_3.9x4.9mm_Pitch1.27mm; PartNumber TCAN334DR
U3: STM32L452CCU6; QFN-48-1EP_7x7mm_P0.5mm_EP5.6x5.6mm; PartNumber STM32L452CCU6
U6: 24AA32; SOT-23-5; PartNumber 24AA32AFT-I/OT
Y1: 8MHz; Resonator_Murata_CSTNE; PartNumber CSTNE8M00GH5C000R0

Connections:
+3V3: C19.1, C32.1, C33.1, C34.1, C35.1, C36.1, R71.2, SWD1.1 (VCC), U2.3 (VCC), U3.1 (VBAT), U3.24 (VDD), U3.36 (VDDUSB), U3.48 (VDD), U6.4 (VCC); also elsewhere on the board
/ISL94202/ALERT: U3.25 (PB12); also elsewhere on the board
/ISL94202/BTN_SIGNAL: U3.29 (PA8); also elsewhere on the board
/MCU/BOOT0: R35.2, U3.44 (PH3)
/MCU/CAN_H: JP3.1, U2.7 (CANH); also elsewhere on the board
/MCU/CAN_L: R69.2, U2.6 (CANL); also elsewhere on the board
/MCU/CAN_RX: U2.4 (RXD), U3.45 (PB8)
/MCU/CAN_STB: U2.8 (STB), U3.2 (PC13)
/MCU/CAN_TX: U2.1 (TXD), U3.46 (PB9)
/MCU/I2C1_SCL: U3.42 (PB6); also elsewhere on the board
/MCU/I2C1_SDA: U3.43 (PB7); also elsewhere on the board
/MCU/I2C2_PULLUP: R55.2, R56.2, U3.20 (PB2)
/MCU/I2C2_SCL: R55.1, U3.21 (PB10), U6.1 (SCL); also elsewhere on the board
/MCU/I2C2_SDA: R56.1, U3.22 (PB11), U6.3 (SDA); also elsewhere on the board
/MCU/LED1: R41.2, U3.27 (PB14)
/MCU/LED2: R42.2, U3.28 (PB15)
/MCU/SPI1_MISO: U3.40 (PB4); also elsewhere on the board
/MCU/SPI1_MOSI: U3.41 (PB5); also elsewhere on the board
/MCU/SPI1_SCK: U3.39 (PB3); also elsewhere on the board
/MCU/SSEL: U3.38 (PA15); also elsewhere on the board
/MCU/SWCLK: SWD1.2 (SWCLK), U3.37 (PA14)
/MCU/SWDIO: SWD1.4 (SWDIO), U3.34 (PA13)
/MCU/USART1_RX: P5.2, U3.31 (PA10)
/MCU/USART1_TX: P5.1, U3.30 (PA9)
/MCU/USART2_RX: U3.13 (PA3); also elsewhere on the board
/MCU/USART2_TX: U3.12 (PA2); also elsewhere on the board
/MCU/USB_D+: D10.1 (IO1); also elsewhere on the board
/MCU/USB_D-: D10.3 (IO2); also elsewhere on the board
/MCU/USB_DM: D10.4 (IO2), U3.32 (PA11)
/MCU/USB_DP: D10.6 (IO1), U3.33 (PA12)
/MCU/~RESET: C31.1, SWD1.5 (NRST), U3.7 (NRST)
/V_EXT: U3.15 (PA5); also elsewhere on the board
GND: C19.2, C27.2, C31.2, C32.2, C33.2, C34.2, C35.2, C36.2, D10.2 (GND), LED1.1 (K), LED2.1 (K), R35.1, SWD1.3 (GND), U2.2 (GND), U3.8 (VSSA), U3.23 (VSS), U3.35 (VSS), U3.47 (VSS), U3.49 (VSS), U6.2 (GND), U6.5 (WP), Y1.2; also elsewhere on the board
unnamed: C27.1, R71.1, U3.9 (VDDA)
unnamed: JP3.2, R69.1
unnamed: LED1.2 (A), R41.1
unnamed: LED2.2 (A), R42.1
unnamed: U3.5 (PH0), Y1.3
unnamed: U3.6 (PH1), Y1.1

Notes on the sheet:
Status LEDs
MCU STM32L452
STM Nucleo SWD and USART
EEPROM
USB ESD protection
CAN transceiver
Tight tolerance for CAN interface

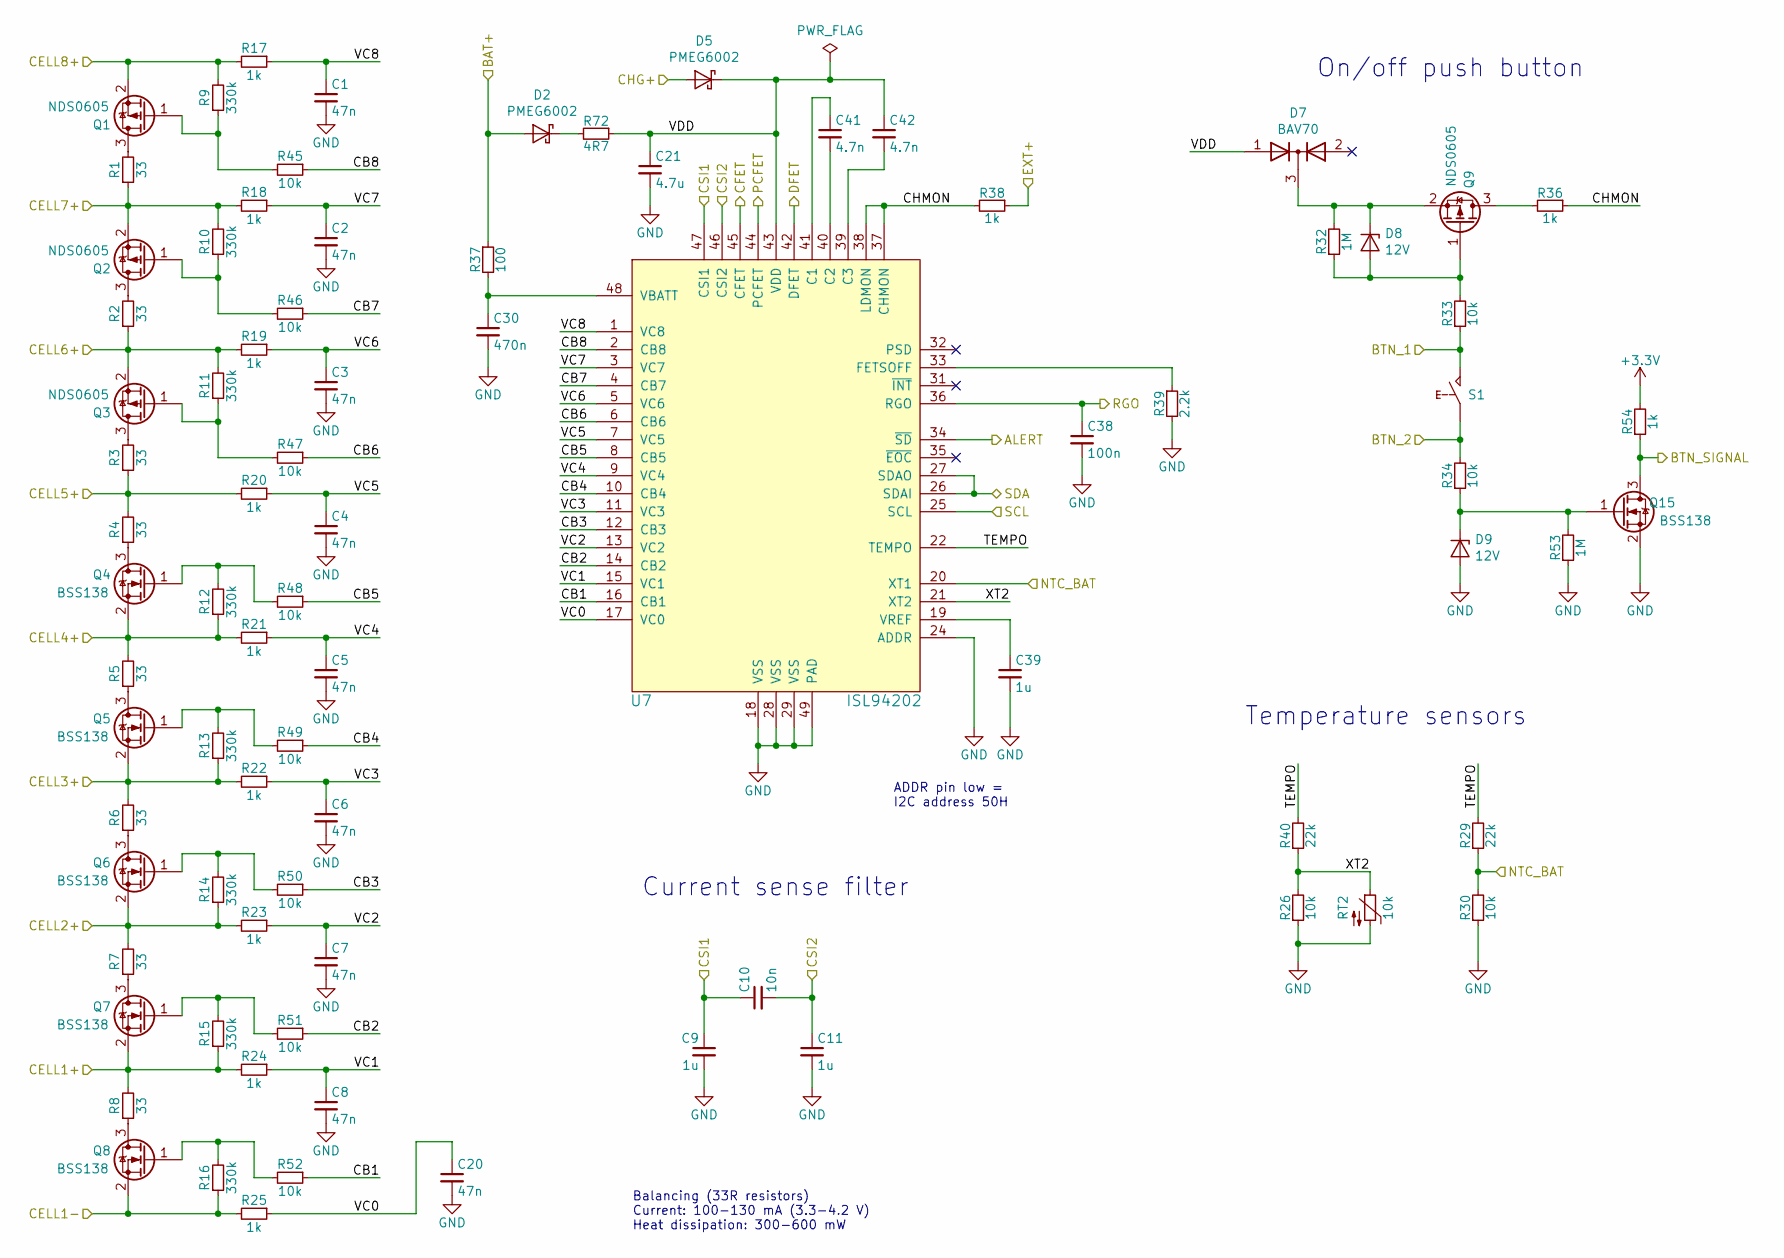
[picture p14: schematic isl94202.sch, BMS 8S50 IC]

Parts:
C1, C2, C3, C4, C5, C6, C7, C8, C20: 47n; C_0603_1608; PartNumber CC0603KRX7R9BB473
C9, C11: 1u; C_0603_1608; PartNumber GRT188R61H105KE13D
C10: 10n; C_0603_1608
C21: 4.7u; C_1206_3216; PartNumber GRM31CR71H475MA12L
C30: 470n; C_0603_1608
C38: 100n; C_0603_1608; PartNumber CC0603KRX7R9BB104
C39: 1u; C_0603_1608
C41, C42: 4.7n; C_0603_1608; PartNumber CC0603KRX7R9BB472
D2, D5: PMEG6002; D_SOD-523; PartNumber PMEG6002EBF
D7: BAV70; SOT-23; PartNumber BAV70LT1G
D8, D9: 12V; D_SOT-23_ANK; PartNumber SZBZX84C12LT3G
Q1, Q2, Q3, Q9: NDS0605; SOT-23; PartNumber NDS0605
Q4, Q5, Q6, Q7, Q8, Q15: BSS138; SOT-23; PartNumber BSS138
R1, R2, R3, R4, R5, R6, R7, R8: 33; R_2010_5025; PartNumber RC2010JK-0733RL
R9, R10, R11, R12, R13, R14, R15, R16: 330k; R_0603_1608; PartNumber RC0603FR-07330KL
R17, R18, R19, R20, R21, R22, R23, R24, R25, R36, R38, R54: 1k; R_0603_1608; PartNumber RC0603FR-071KL
R26, R30, R33, R34, R45, R46, R47, R48, R49, R50, R51, R52: 10k; R_0603_1608; PartNumber RC0603FR-0710KL
R29, R40: 22k; R_0603_1608; PartNumber RC0603FR-0722KL
R32: 1M; R_0603_1608
R37: 100; R_0603_1608; PartNumber RC0603FR-07100RL
R39: 2.2k; R_0603_1608; PartNumber RC0603FR-072K2L
R53: 1M; R_0603_1608; PartNumber RC0603FR-071ML
R72: 4R7; R_0603_1608; PartNumber RC0603FR-071KL
RT2: 10k; R_0603_1608; PartNumber NTCG163JF103FT1S
S1: SW_PUSH; SW_SPST_6mm
U7: ISL94202; QFN-48-1EP_6x6mm_P0.4mm_EP4.3x4.3mm; PartNumber ISL94202IRTZ-T7A

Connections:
+3V3: R54.2; also elsewhere on the board
/BAT+: C9.1, C10.1, D2.2 (A), R37.1, U7.47 (CSI1); also elsewhere on the board
/EXT+: R38.1; also elsewhere on the board
/ISL94202/ALERT: U7.34 (~SD); also elsewhere on the board
/ISL94202/BTN_1: R33.1, S1.2; also elsewhere on the board
/ISL94202/BTN_2: R34.2, S1.1; also elsewhere on the board
/ISL94202/BTN_SIGNAL: Q15.3 (D), R54.1; also elsewhere on the board
/ISL94202/CB1: R52.1, U7.16 (CB1)
/ISL94202/CB2: R51.1, U7.14 (CB2)
/ISL94202/CB3: R50.1, U7.12 (CB3)
/ISL94202/CB4: R49.1, U7.10 (CB4)
/ISL94202/CB5: R48.1, U7.8 (CB5)
/ISL94202/CB6: R47.1, U7.6 (CB6)
/ISL94202/CB7: R46.1, U7.4 (CB7)
/ISL94202/CB8: R45.1, U7.2 (CB8)
/ISL94202/CELL1+: Q7.2 (S), R8.2, R15.1, R24.2; also elsewhere on the board
/ISL94202/CELL1-: Q8.2 (S), R16.1, R25.2; also elsewhere on the board
/ISL94202/CELL2+: Q6.2 (S), R7.2, R14.1, R23.2; also elsewhere on the board
/ISL94202/CELL3+: Q5.2 (S), R6.2, R13.1, R22.2; also elsewhere on the board
/ISL94202/CELL4+: Q4.2 (S), R5.2, R12.1, R21.2; also elsewhere on the board
/ISL94202/CELL5+: R3.1, R4.2, R20.2; also elsewhere on the board
/ISL94202/CELL6+: Q3.2 (S), R2.1, R11.2, R19.2; also elsewhere on the board
/ISL94202/CELL7+: Q2.2 (S), R1.1, R10.2, R18.2; also elsewhere on the board
/ISL94202/CELL8+: Q1.2 (S), R9.2, R17.2; also elsewhere on the board
/ISL94202/CFET: U7.45 (CFET); also elsewhere on the board
/ISL94202/CHG+: D5.2 (A); also elsewhere on the board
/ISL94202/CHMON: R36.1, R38.2, U7.37 (CHMON), U7.38 (LDMON)
/ISL94202/CSI2: C10.2, C11.1, U7.46 (CSI2); also elsewhere on the board
/ISL94202/DFET: U7.42 (DFET); also elsewhere on the board
/ISL94202/NTC_BAT: R29.1, R30.2, U7.20 (XT1); also elsewhere on the board
/ISL94202/PCFET: U7.44 (PCFET); also elsewhere on the board
/ISL94202/RGO: C38.1, U7.36 (RGO); also elsewhere on the board
/ISL94202/TEMPO: R29.2, R40.2, U7.22 (TEMPO)
/ISL94202/VC0: C20.1, R25.1, U7.17 (VC0)
/ISL94202/VC1: C8.1, R24.1, U7.15 (VC1)
/ISL94202/VC2: C7.1, R23.1, U7.13 (VC2)
/ISL94202/VC3: C6.1, R22.1, U7.11 (VC3)
/ISL94202/VC4: C5.1, R21.1, U7.9 (VC4)
/ISL94202/VC5: C4.1, R20.1, U7.7 (VC5)
/ISL94202/VC6: C3.1, R19.1, U7.5 (VC6)
/ISL94202/VC7: C2.1, R18.1, U7.3 (VC7)
/ISL94202/VC8: C1.1, R17.1, U7.1 (VC8)
/ISL94202/VDD: C21.1, C42.1, D5.1 (K), D7.1 (A), R72.1, U7.43 (VDD)
/ISL94202/XT2: R26.2, R40.1, RT2.1, U7.21 (XT2)
/MCU/I2C2_SCL: U7.25 (SCL); also elsewhere on the board
/MCU/I2C2_SDA: U7.26 (SDAI), U7.27 (SDAO); also elsewhere on the board
GND: C1.2, C2.2, C3.2, C4.2, C5.2, C6.2, C7.2, C8.2, C9.2, C11.2, C20.2, C21.2, C30.2, C38.2, C39.2, D9.2 (A), Q15.2 (S), R26.1, R30.1, R39.2, R53.1, RT2.2, U7.18 (VSS), U7.24 (ADDR), U7.28 (VSS), U7.29 (VSS), U7.49 (PAD); also elsewhere on the board
unnamed: C30.1, R37.2, U7.48 (VBATT)
unnamed: C39.1, U7.19 (VREF)
unnamed: C41.1, U7.41 (C1)
unnamed: C41.2, U7.40 (C2)
unnamed: C42.2, U7.39 (C3)
unnamed: D2.1 (K), R72.2
unnamed: D7.3 (K), D8.1 (K), Q9.2 (S), R32.2
unnamed: D8.2 (A), Q9.1 (G), R32.1, R33.2
unnamed: D9.1 (K), Q15.1 (G), R34.1, R53.2
unnamed: Q1.1 (G), R9.1, R45.2
unnamed: Q1.3 (D), R1.2
unnamed: Q2.1 (G), R10.1, R46.2
unnamed: Q2.3 (D), R2.2
unnamed: Q3.1 (G), R11.1, R47.2
unnamed: Q3.3 (D), R3.2
unnamed: Q4.1 (G), R12.2, R48.2
unnamed: Q4.3 (D), R4.1
unnamed: Q5.1 (G), R13.2, R49.2
unnamed: Q5.3 (D), R5.1
unnamed: Q6.1 (G), R14.2, R50.2
unnamed: Q6.3 (D), R6.1
unnamed: Q7.1 (G), R15.2, R51.2
unnamed: Q7.3 (D), R7.1
unnamed: Q8.1 (G), R16.2, R52.2
unnamed: Q8.3 (D), R8.1
unnamed: Q9.3 (D), R36.2
unnamed: R39.1, U7.33 (FETSOFF)

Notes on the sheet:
Balancing (33R resistors) Current: 100-130 mA (3.3-4.2 V) Heat dissipation: 300-600 mW
Current sense filter
Temperature sensors
On/off push button
ADDR pin low = I2C address 50H

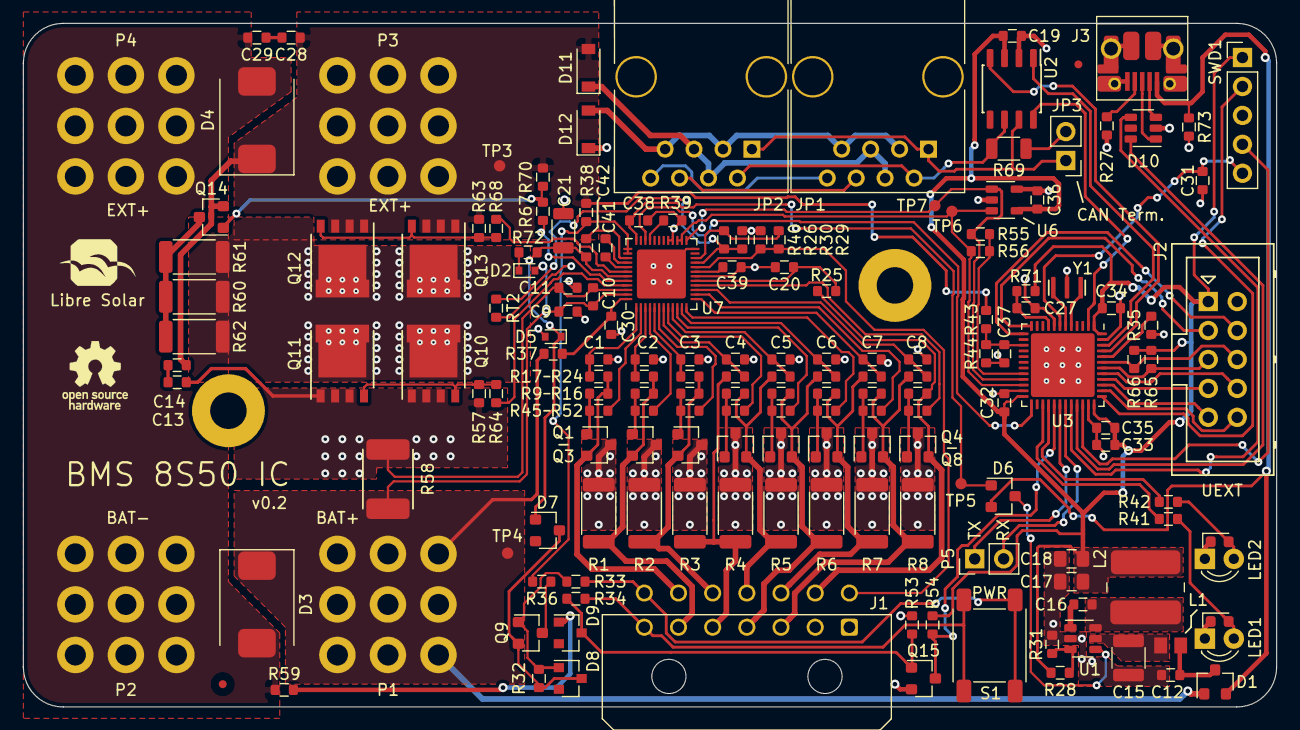
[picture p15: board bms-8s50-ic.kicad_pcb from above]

Board: 2 copper layers, 110.0 x 60.0 mm, 169 parts (0 on the bottom side), 126 nets.

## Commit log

2019-08-12 Draft housing design added
    [bms-8s50-ic.FCStd]
2020-05-08 Fix issues found during testing (v0.1.1)
    - Add BAT+/- and EXT+/- markings to terminals (#2)
    - Change C30 to 470nF (#5)
    - Add C20 (47nF) at VC0 pin (#5)
    - Add C21 and R72 for proper low-pass filter of VDD (#5)
    - Change C39 at VREF to 1uF (#5)
    - Add R70: Pull-down for PCHG FET (#5)
    - Add R73: Weak pull-down for 5V supply (#6)
    [bms-8s50-ic.kicad_pcb, bms-8s50-ic.sch, isl94202.sch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]
2020-06-08 Add KiCad symbol cache and remove rescue lib
    [power_supply.sch]
2021-02-14 Update to v0.2
    - Switch to STM32L452 MCU (STM32F072 has too little RAM for CAN ISO-TP etc.)
    - Add CAN termination jumper
    - Add CAN bus power supply diodes
    - Update CAN connector to match LS.bus spec
    - Add interactive BOM and CSV BOM to build directory
    - Add additional thermal vias with 0.2mm diameter under MOSFETs
    [bms-8s50-ic.kicad_pcb, bms-8s50-ic.sch, bms-8s50-ic_bom.csv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]

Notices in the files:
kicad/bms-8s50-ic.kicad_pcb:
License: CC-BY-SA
